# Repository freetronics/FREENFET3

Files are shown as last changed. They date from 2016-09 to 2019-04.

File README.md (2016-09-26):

Freetronics FreeNFET Addressable 3x N-MOSFET Module
====================================================
Copyright 2016 Freetronics Pty Ltd  
Freetronics site:  www.freetronics.com  
Freetronics email: info@freetronics.com  

These are FETs with a brain! Includes 3 x NTD5867NL N-channel MOSFETs and
a WS2811 addressable LED driver. That means you can connect the module
and address it just as if it was a NeoPixel or other WS28xx RGB LED, 
except that instead of controlling an LED, you're controlling 3 high-power
MOSFETs.

This smart module can be daisy-chained, so you can connect a number of
these together in a string and drive each of them individually from your
microcontroller.

Compatible with various Arduino libraries for the WS2811, including
the FastLED library and the NeoPixel library. Simply control the "red",
"green", and "blue" channels to control the FETs.

Features:

 * Switch up to 60V / 18A DC per FET.
 * Requires just 1 data connection.
 * PWM control of the FETs.
 * Input and output headers on opposite sides of the board for easy
   daisy-chaining.

More information is available at:

  http://www.freetronics.com.au/freenfet3

INSTALLATION
------------
The design is saved as an EAGLE project. EAGLE PCB design software is
available from www.cadsoftusa.com free for non-commercial use. To use
this project download it and place the directory containing these files
into the "eagle" directory on your computer.

DISTRIBUTION
------------
The specific terms of distribution of this project are governed by the
license referenced below.

LICENSE
-------
Licensed under the TAPR Open Hardware License (www.tapr.org/OHL).
The "license" folder within this repository also contains a copy of
this license in plain text format.

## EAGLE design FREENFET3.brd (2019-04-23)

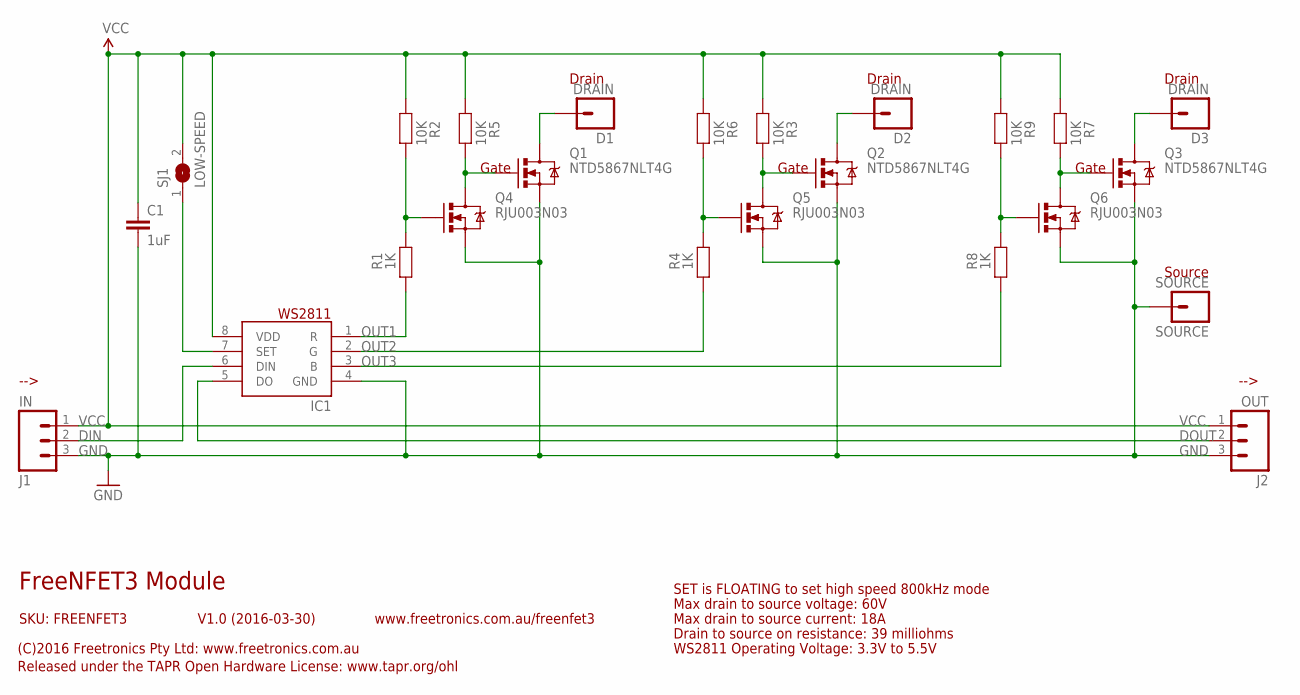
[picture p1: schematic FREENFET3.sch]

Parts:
C1: 1uF; 0603
D1, D2, D3: DRAIN; 1X01LARGE
IC1: WS2811-SOP8; SO08-SKINNYPADS
J1: IN; 1X03
J2: OUT; 1X03
Q1, Q2, Q3: NTD5867NLT4G; DPACK
Q4, Q5, Q6: RJU003N03; SOT32-3
R1, R4, R8: 1K; 0603
R2, R3, R5, R6, R7, R9: 10K; 0603
SJ1: LOW-SPEED; SJ
SOURCE: SOURCE; 1X01LARGE

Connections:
D: D1.1, Q1.2 (D)
D1: D2.1, Q2.2 (D)
D2: D3.1, Q3.2 (D)
DIN: IC1.6 (DIN), J1.2
DOUT: IC1.5 (DO), J2.2
GND: C1.2, IC1.4 (GND), J1.3, J2.3, Q1.3 (S), Q2.3 (S), Q3.3 (S), Q4.2 (S), Q5.2 (S), Q6.2 (S), SOURCE.1
unnamed: Q2.1 (G), Q5.3 (D), R3.1
unnamed: Q4.1 (G), R1.1, R2.1
unnamed: Q1.1 (G), Q4.3 (D), R5.1
unnamed: Q5.1 (G), R4.1, R6.1
unnamed: Q3.1 (G), Q6.3 (D), R7.1
unnamed: Q6.1 (G), R8.1, R9.1
unnamed: IC1.7 (SET), SJ1.1
OUT1: IC1.1 (R), R1.2
OUT2: IC1.2 (G), R4.2
OUT3: IC1.3 (B), R8.2
VCC: C1.1, IC1.8 (VDD), J1.1, J2.1, R2.2, R3.2, R5.2, R6.2, R7.2, R9.2, SJ1.2

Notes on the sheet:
FreeNFET3 Module
V1.0 (2016-03-30)
SKU: FREENFET3
(C)2016 Freetronics Pty Ltd: www.freetronics.com.au
Released under the TAPR Open Hardware License: www.tapr.org/ohl
www.freetronics.com.au/freenfet3
WS2811 Operating Voltage: 3.3V to 5.5V
-->
SET is FLOATING to set high speed 800kHz mode
Max drain to source current: 18A
Drain
Gate
Source
Max drain to source voltage: 60V
Drain to source on resistance: 39 milliohms

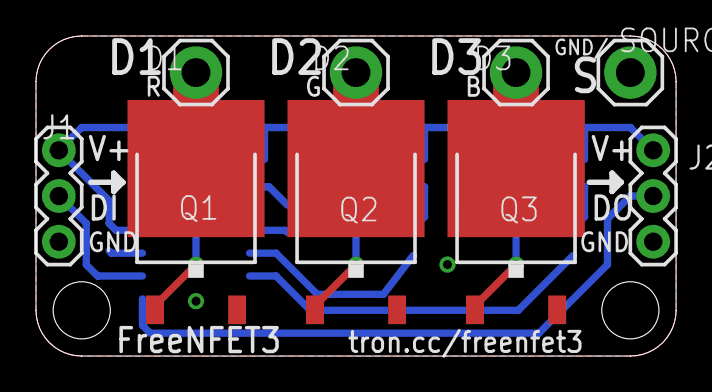
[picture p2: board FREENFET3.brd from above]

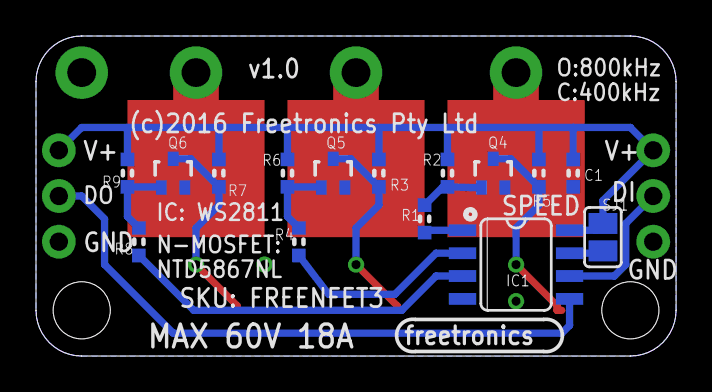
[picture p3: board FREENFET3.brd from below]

Board: 2 copper layers, 35.6 x 17.8 mm, 24 parts (15 on the bottom side), 17 nets.

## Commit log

2016-09-26 Initial import
    [FREENFET3.brd, FREENFET3.sch]
2019-04-23 Final layout
    [FREENFET3.brd, FREENFET3.sch]
